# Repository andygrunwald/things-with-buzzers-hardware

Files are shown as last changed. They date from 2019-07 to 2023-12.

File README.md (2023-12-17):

# things with buzzers: hardware

Build your own hardware game show buzzers and do [awesome things](#things-you-can-do-with-buzzers) with it! 🚀

This repository contains everything you need to build hardware buzzers and connecting them with your software.
Start today having fun, and make people happy by providing them an unforgettable time.

> For even more context, we recommend reading [things with buzzers: building them](https://andygrunwald.com/blog/things-with-buzzers-building-them/).

<p align="center">
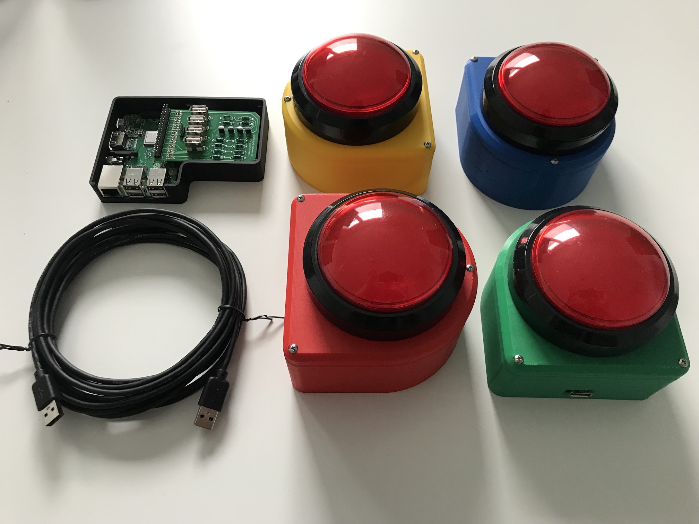
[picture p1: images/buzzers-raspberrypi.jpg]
The finished product: Four buzzers, a Raspberry Pi incl. hat
  
</p>

## Table of Contents

- [How we build and run them](#how-we-build-and-run-them)
- [What we need / Bill of materials (BOM)](#what-we-need--bill-of-materials-bom)
- [Buzzers](#buzzers)
- [Raspberry Pi Hat](#raspberry-pi-hat)
  - [GPIO pin out](#gpio-pin-out)
- [Raspberry Pi](#raspberry-pi)
- [Custom Raspberry Pi case](#custom-raspberry-pi-case)
- [How we can test the buzzers (with software)](#how-we-can-test-the-buzzers-with-software)
- [The result](#the-result)
- [Things you can do with buzzers](#things-you-can-do-with-buzzers)
- [Alternative hardware buzzer projects](#alternative-hardware-buzzer-projects)
- [Contribute](#contribute)
- [Acknowledgments](#acknowledgments)

## How we build and run them

We built four game show buzzers in four different colors (red, green, blue, yellow).
The buzzer cases are self-printed with a 3D-Printer.
Each buzzer case has a female USB connector embedded.

The central control unit is a Raspberry Pi 3 Model B+ (following _Pi_) with a custom build hat module (circuit board).
The hat module offers four female USB connectors and maps them onto the GPIO of the Pi.

Each buzzer connects via a USB cable to the Pi hat.
On the Pi, we can place software and read the buzzer signals (e.g., buzzer pressed) and react on this.

If the software (running on the Pi) offers a UI and the Pi connects to a network (or opens up a new network), a client can connect to it.
As a small software example: Show in the UI which button is pressed.

It is how it looks like:

<p align="center">
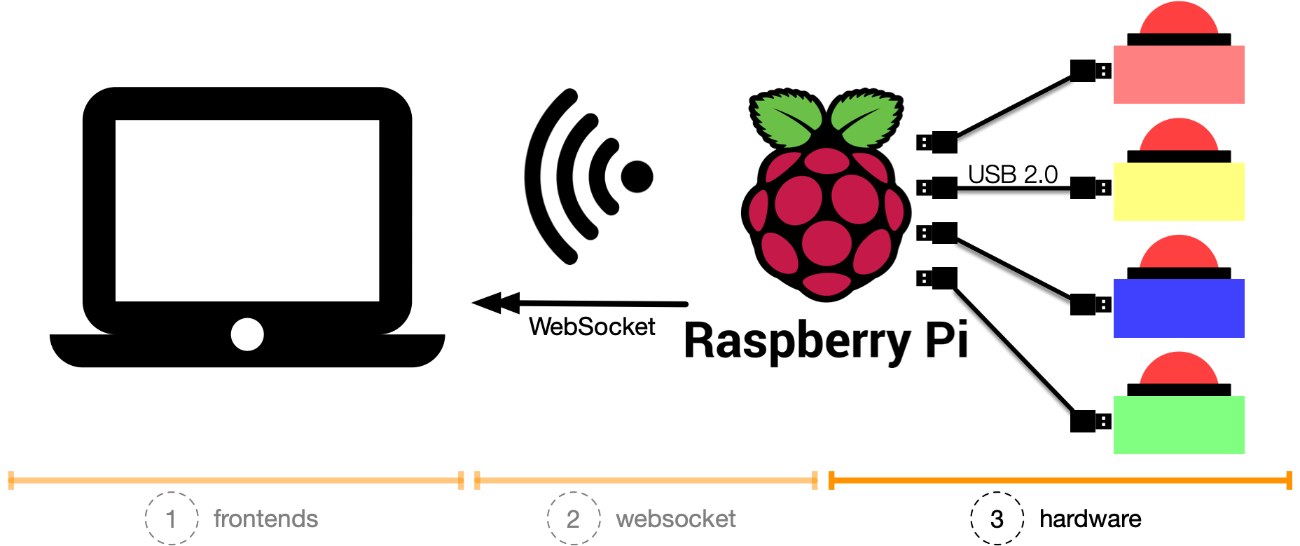
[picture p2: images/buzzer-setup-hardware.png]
The complete setup: Buzzer -> USB -> Raspberry Pi -> Computer
  
</p>

_You are missing the context, what this is all about?_
Have a look at

* [(1) things with buzzers: Jeopardy! frontend](https://github.com/andygrunwald/things-with-buzzers-jeopardy)
* [(1) things with buzzers: sports competition frontend](https://github.com/andygrunwald/things-with-buzzers-sports-competition)
* [(2) things with buzzers: websocket](https://github.com/andygrunwald/things-with-buzzers-websocket)

## What we need / Bill of materials (BOM)

To replicate this project and build your buzzers, you need a couple of things.
We have created a complete list of what you need, a so-called _Bill of material (BOM)_.

Check it out: [Bill of materials (BOM)](./bill-of-materials.md).

## Buzzers

First, we start with the buzzer case and print it with a 3D printer.
Printing instructions / Step files can be found in the [3d-models folder for the buzzer cases](./3d-models/buzzer/).
Feel free to choose the color of your printing material for the right look.
Go ahead and print!

If you are new to 3D printing, step files are printing instructions.
You can few and edit them with software like [Fusion 360 from Autodesk](https://www.autodesk.com/products/fusion-360/free-trial) (they offer [a free version for startups and hobbyists](https://www.autodesk.com/campaigns/fusion-360-for-hobbyists)).

<p align="center">
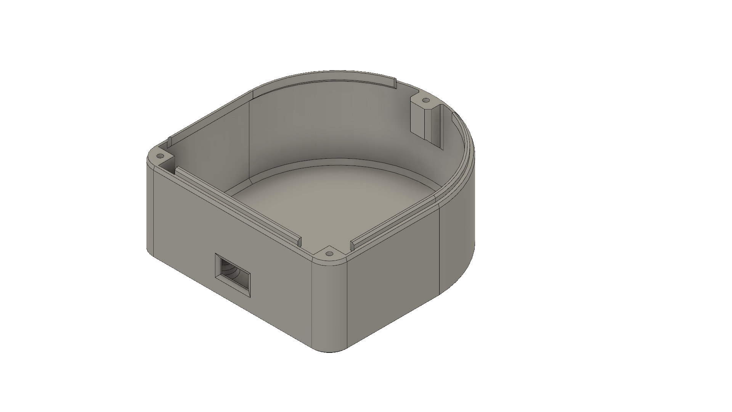
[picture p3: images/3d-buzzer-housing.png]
3D model of the buzzer case
  
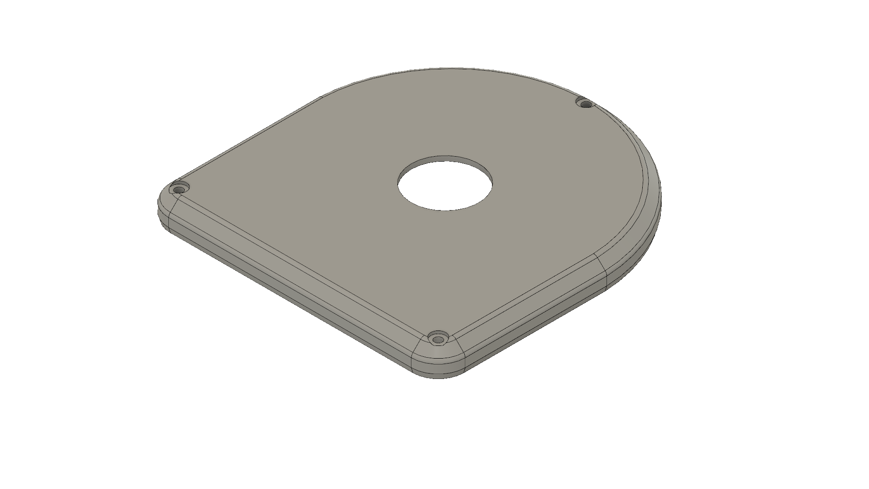
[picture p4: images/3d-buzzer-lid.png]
3D model of the buzzer lid
  
</p>

Next step would be to build the small circuit board that connects the buzzer with the USB socket:

<p align="center">
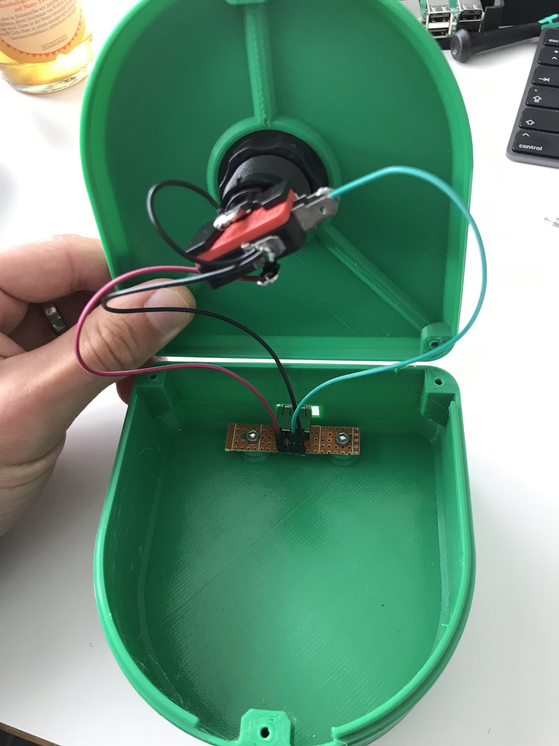
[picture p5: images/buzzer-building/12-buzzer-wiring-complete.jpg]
Buzzer wired internally
  
</p>

Check out the **step-by-step image guide on how to build this** in our [buzzer building folder](./images/buzzer-building/README.md).

Congratulations, you build your first game show buzzer. How awesome is this?

## Raspberry Pi Hat

Second, we build our custom Pi hat.
The buzzers are connected to the GPIO on the Raspberry Pi.
For convenience reasons, we built a custom Pi hat with USB sockets.
This makes it easier to assemble and disassemble the setup.

<p align="center">
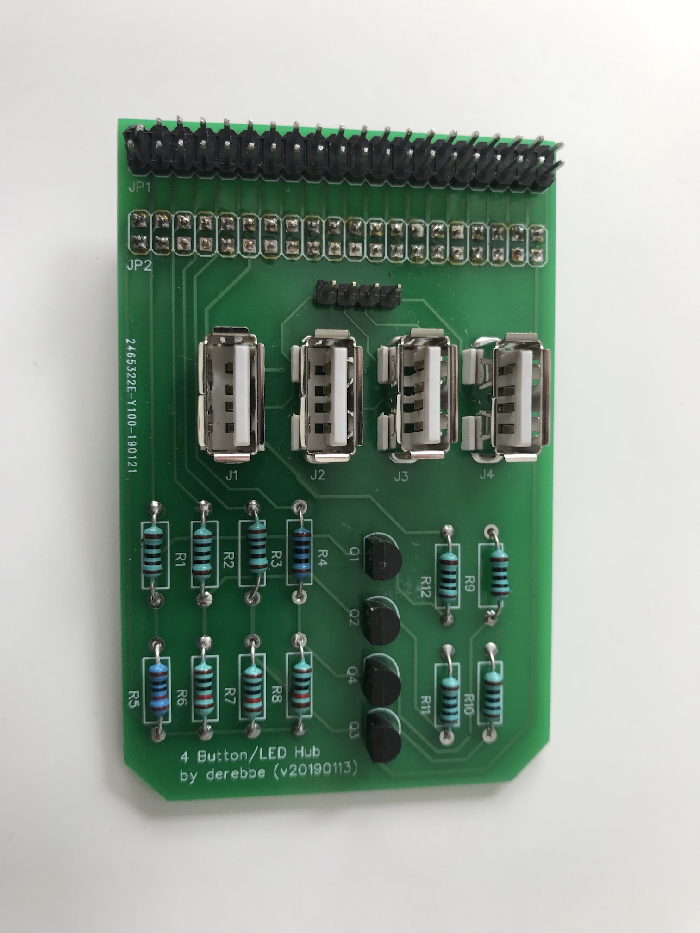
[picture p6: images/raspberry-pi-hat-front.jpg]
Raspberry Pi hat front view
  
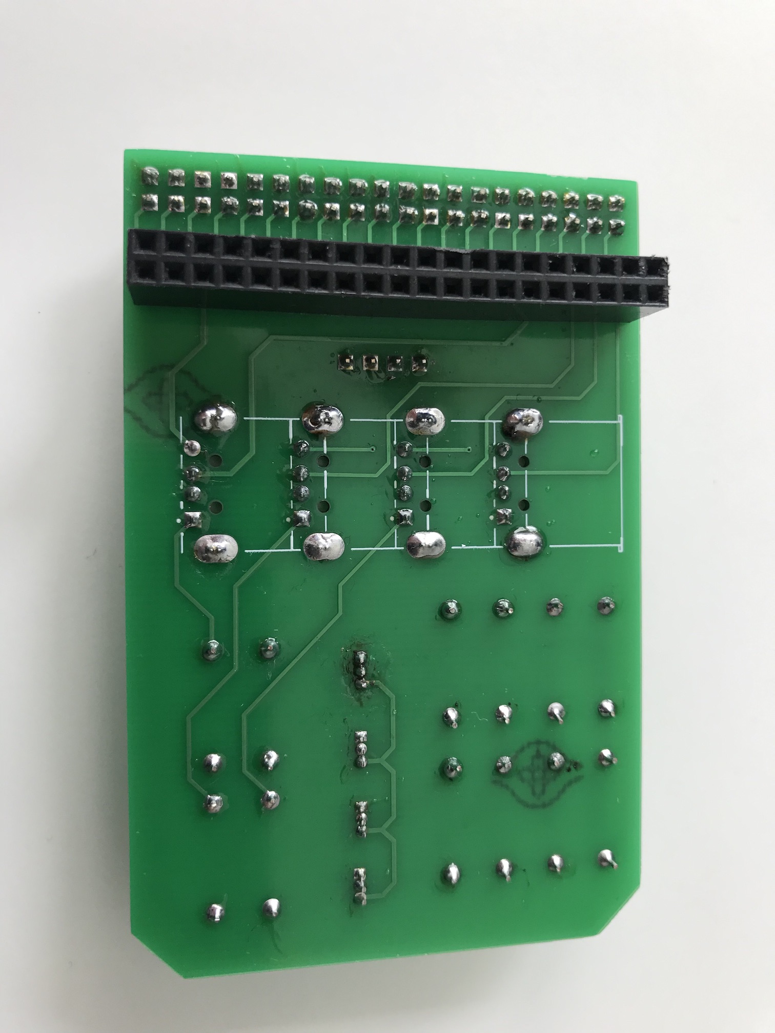
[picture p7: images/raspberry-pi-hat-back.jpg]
Raspberry Pi hat back view
  
</p>

We used [EasyEDA](https://easyeda.com/) to design the printed circuit board (PCB).
**We made the project public. Check it out at [RPI 4Button LED HUB from derebbe @ EasyEDA](https://easyeda.com/derebbe/RPI-4Button-LED-HUB)**.

The EasyEDA project shows you which resistor, transistor or pin has to be placed.
Furthermore, you can [order the pre-designed PCB at EasyEDA](https://docs.easyeda.com/en/PCB/Order-PCB).
Pre-designed, in this case, means: You get the circuit board and need to place the components on it.
All wholes are pre-defined, and all components are connected already.

If you want to create the circuit board on your own, you can find all Gerber files in our [Raspberry Pi Hat Gerber folder](./raspberry-pi-hat-gerber/).
You can also do a fresh export from [our project on EasyEDA](https://easyeda.com/derebbe/RPI-4Button-LED-HUB).

If this is done, place the hat on the GPIOs on top of the Raspberry Pi.
By this, you are good to go!

### GPIO pin out

Placing the hat on the pi, you connect the buzzers with the GPIO.
To react with your software on buzzer pushed, you need to know which pins your software need to listen on.
The [GPIO pin out assignment](https://www.raspberrypi.org/documentation/usage/gpio/) looks like the following:

| USB Port  | GPIO Pin (BCM) | GPIO Pin (Physical) | Purpose |
| --- | --- | --- | --- |
| Port #1 | 21 | 40 | Button  |
| Port #1 | 26 | 37 | LED |
| Port #2 | 20 | 38 | Button  |
| Port #2 | 19 | 35 | LED |
| Port #3 | 16 | 36 | Button  |
| Port #3 | 13 | 33 | LED |
| Port #4 | 12 | 32 | Button  |
| Port #4 | 6 | 31 | LED |

The [pin-out mapping from the go-rpio documentation](https://godoc.org/github.com/stianeikeland/go-rpio) is super helpful.

## Raspberry Pi

Third and last step lets set up the Pi!
On the Raspberry Pi (following _Pi_) itself, we install a [standard Raspbian Lite operating system](https://www.raspberrypi.org/downloads/raspbian/) without any desktop functionality.

To access the Pi from an external client (e.g., laptop or mobile phone) you should connect it to a network.
Either to an existing one via a typical RJ45 LAN cable or a wireless network (can be done via [`raspi-config`](https://www.raspberrypi.org/documentation/configuration/raspi-config.md)).
If you want to run it completely independent and maybe offline, we recommend to [configure the Pi as a wireless access point](https://www.raspberrypi.org/documentation/configuration/wireless/access-point.md).

Add the Pi hat onto the GPIO and move on to your first software tests.

## Custom Raspberry Pi case

A Pi with a hat consumes more space.
Especially with a custom hat, it is hard to find a case that fits.
That's why we printed our own.

Printing instructions / Step files can be found in the 3d-models folder for the raspberry pi case.
Feel free to choose the color of your printing material for the right look.
Go ahead and print!

<p align="center">
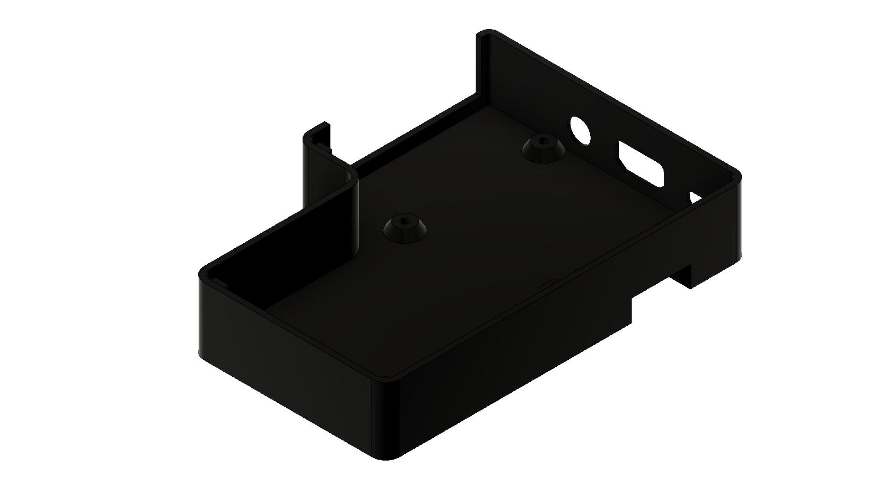
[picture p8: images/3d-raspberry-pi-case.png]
3D model of the custom Raspberry Pi case
  
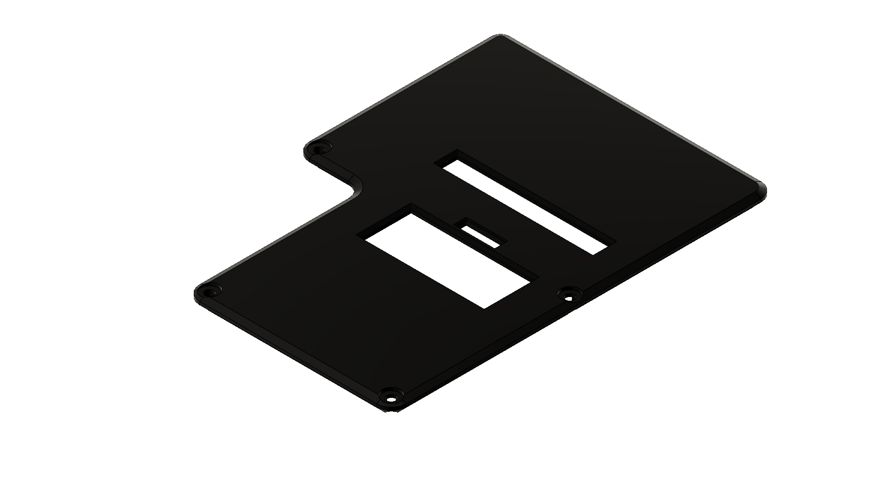
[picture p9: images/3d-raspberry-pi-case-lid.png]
3D model of the custom Raspberry Pi case lid
  
</p>

## How we can test the buzzers (with software)

Set everything up.
Connect the buzzers with the Raspberry Pi and start the machine.
It is time to test our new hardware with software ❤️.

Have a look at our test scripts and test applications.
Choose the one you like the most (or by roll a dice):

* [test script written in Python 🐍](./software/python/)
* [test application written in Go](./software/go/)

If everything works out, it is okay to freak out and run naked through your flat.
You deserved it. You have built the foundation for more.
Don't stop. Find out [what you can do with buzzers](#things-you-can-do-with-buzzers).

## The result

We have set up a quick demo setup.
Have a quick look at this video: [things with buzzers: hardware showcase @ YouTube](https://youtu.be/pAQNX0Fhxk4).

## Things you can do with buzzers

* [Running a Jeopardy! game show](https://andygrunwald.com/blog/things-with-buzzers-playing-jeopardy/)
* [Stopping athletes time during a sports event](https://andygrunwald.com/blog/things-with-buzzers-a-sports-competition/)

## Alternative hardware buzzer projects

* [Slim one handed buzzers by Ross and Garrett](https://github.com/gdsimco/JParty-with-buzzers/blob/8b5948cd840acf981036fda1b671626e5d60780b/physicalbuzzers/README.md)

## Contribute

If you are a maker or an engineer or just someone who wants to create and ship awesome things: *Go ahead and make this better*.
Feel free to fork it and play your changes back via a [Pull Request](https://help.github.com/en/articles/about-pull-requests).

If you ...
* are unsure
* plan to do a more significant rework
* want to get feedback about the idea before you put the effort in

[Open an issue](https://github.com/andygrunwald/things-with-buzzers-hardware/issues/new) and let us talk about your idea.

You have built your own buzzers and did awesome things with it?
Write an article in your blog, or tell us the story in an issue or make a Pull Request with a Markdown file.
But tell us. Let us know. Inspire us!

We believe that we can do more together. Let's to it together! 🚀

## Acknowledgments

A big thank you to [Lars Heß / @lhess](https://github.com/lhess) and [Matthias Endler / @mre](https://github.com/mre).
Without them, this project would not happen.

Lars has designed and built the complete hardware.
Matthias helped a lot with the software and motivation part 😀

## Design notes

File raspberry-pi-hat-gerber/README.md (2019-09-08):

# Raspberry Pi Hat Gerber Files

_If you don't know what this is, have a look at the [main README](../README.md)_

Gerber files to build the Rasberry Pi Hat shown below.
Also available at the [RPI 4Button LED HUB from derebbe @ EasyEDA](https://easyeda.com/derebbe/RPI-4Button-LED-HUB) project.

<p align="center">
  Raspberry Pi hat front view
</p>

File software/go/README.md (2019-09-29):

# Go test application

_If you don't know what this is, have a look at the [main README](../../README.md)_

The test application is written in [Go](https://golang.org/).

## Compile it for the Raspberry Pi

```sh
GOARM=7 GOARCH=arm GOOS=linux go build -o "twb-hardware-buzzer-push"
```

## Deployment on your Raspberry Pi

If you are on a Mac or Linux machine, you can deploy this script by using `scp` onto your Raspberry Pi:

```sh
scp -r twb-hardware-buzzer-push pi@192.168.4.1:twb-hardware-buzzer-push
```

In our example, the target Pi has the IP address `192.168.4.1`.

## Start the application

Login into the Pi, switch to the correct folder, and execute:

```sh
sudo ./twb-hardware-buzzer-push
```

## The result

If everything works fine, the result should look like ...

<p align="center">
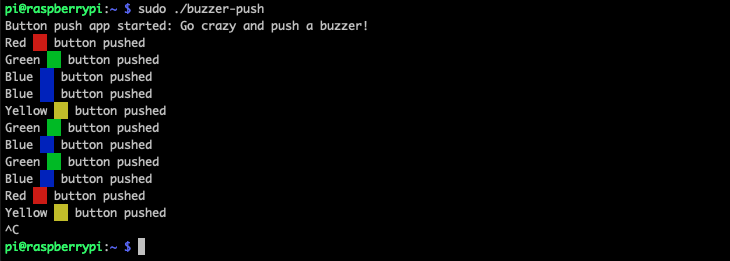
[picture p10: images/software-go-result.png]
Result of the software test with Go
  
</p>

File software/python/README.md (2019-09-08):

# Python test script

_If you don't know what this is, have a look at the [main README](../../README.md)_

The test script is written in [Python](https://www.python.org/).

## Deployment on your Raspberry Pi

If you are on a Mac or Linux machine, you can deploy this script by using `scp` onto your Raspberry Pi:

```sh
scp -r * pi@192.168.4.1:python-test/
```

In our example, the target Pi has the IP address `192.168.4.1`.

## Start the script

Login into the Pi, switch to the correct folder, and execute:

```sh
sudo python button-push.py
```

## The result

If everything works fine, the result should look like ...

<p align="center">
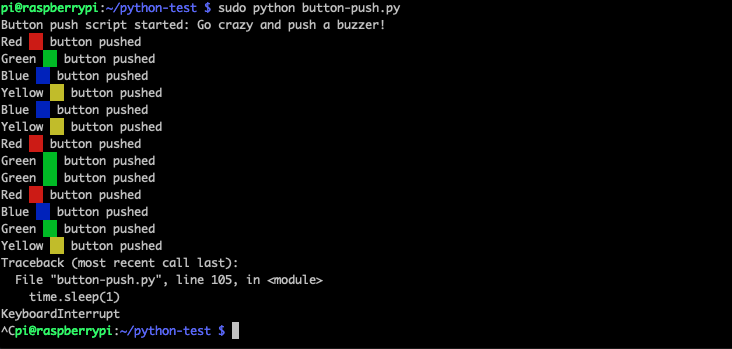
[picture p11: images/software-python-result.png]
Result of the software test with Python
  
</p>

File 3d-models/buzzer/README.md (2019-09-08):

# 3D Models for the buzzer case

_If you don't know what this is, have a look at the [main README](../../README.md)_

Step files to 3D print a case for game show buzzers.

<p align="center">
  3D model of the buzzer case
  3D model of the buzzer lid
</p>

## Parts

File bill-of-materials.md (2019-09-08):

# Bill of materials (BOM)

_If you don't know what this is, have a look at the [main README](README.md)_

Everything that you need to build your buzzers and replicate this project.

We aim to categorize the materials per component.
The links are just for showcase reasons and might not link to the cheapest shops.
Please do your research depending on your country of living where to buy the materials best.

PS: If you don't own everything yourself (like more expensive equipment like a 3D printer, you can reach out to a local [Hackerspace](https://en.wikipedia.org/wiki/Hackerspace) or a [Fab lab](https://en.wikipedia.org/wiki/Fab_lab) in your area.

## General equipment

Things you need in general:

* A Soldering iron and solder
* Fine mechanics tooling to work with electronic components (e.g., cables, resistor)
* A 3D printer

## Buzzer

This list of materials is to build one buzzer.
Please multiply it according to the number of buzzers you want to build.

* Print material for a 3D printer in a color of your choice (the button case)
* The buzzer itself (e.g., on [ebay germany](https://www.ebay.de/itm/100mm-Selbstruck-Convex-Taster-Spiel-Vending-Machine-Control-Microswitch/182433206826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) or [AliExpress](https://www.aliexpress.com/item/32757761221.html?spm=a2g1y.12024536.productList_117902197.pic_9)) - Make sure that they are 100mm big and not the small arcade buttons
* [A USB male connector](https://www.amazon.com/USB-Connector-Conwork-Straight-Replacement/dp/B072MCHX41?th=1)
* [Breadboard jumper wires](https://www.amazon.com/Foxnovo-Breadboard-Jumper-Wires-Female/dp/B00PBZMN7C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)
* [Pin header connectors](https://www.amazon.com/Glarks-Connector-Assortment-Stackable-Breakaway/dp/B07CWSXY7P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)
* A small piece of a [circuit board](https://www.amazon.com/uxcell-Universal-Printed-Circuit-Soldering/dp/B07FK6TDD5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) (to cut and solder)
* Three small screws

## Raspberry Pi hat

The Pi hat is only needed and built once (for four buzzers).

PS: The circuit board itself (without components on it) is fully designed at [our EasyEDA project](https://easyeda.com/derebbe/RPI-4Button-LED-HUB) and can be ordered from there. By this, you don't have to connect the components by yourself, only add them onto the board.

* A [circuit board](https://www.amazon.com/uxcell-Universal-Printed-Circuit-Soldering/dp/B07FK6TDD5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) (to cut and solder)
* 4 x [USB male connector](https://www.amazon.com/USB-Connector-Conwork-Straight-Replacement/dp/B072MCHX41?th=1)
* 4 x resistor 100Ω
* 4 x resistor 10KΩ
* 4 x resistor 470Ω
* 4 x transistor npn (BJT)
* 1 x male 2x20 [Pin Headers](https://www.amazon.com/dp/B074HVBTZ4/ref=psdc_172544_t2_B07CWSXY7P)
* 1 x female 2x20 [Pin Headers](https://www.amazon.com/dp/B074HVBTZ4/ref=psdc_172544_t2_B07CWSXY7P)
* 1 x male 1x4 [Pin Headers](https://www.amazon.com/dp/B074HVBTZ4/ref=psdc_172544_t2_B07CWSXY7P)

## Miscellaneous

* A Raspberry Pi 3 Model B+ (or a newer one with the same layout)
* 5m USB 2.0 cables (don't need to be the best quality when it comes to data transfer speed, we only use USB for convenience reasons and to transfer the push signal)

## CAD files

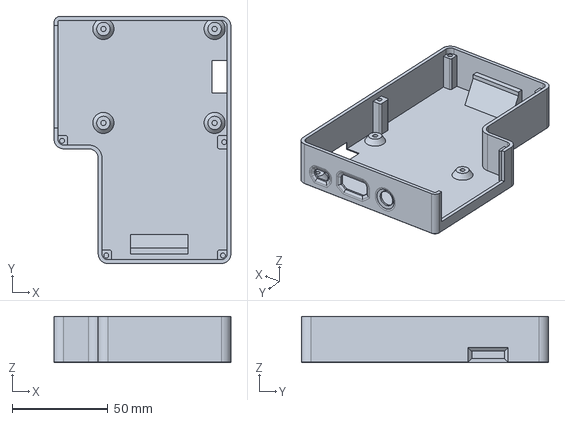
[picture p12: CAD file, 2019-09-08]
3d-models/raspberry-pi-case/CaseMain.step
92.2 x 128.8 x 24.0 mm

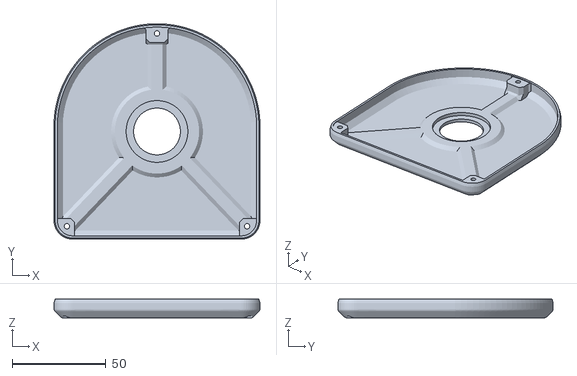
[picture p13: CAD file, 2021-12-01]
3d-models/buzzer/BuzzerLidV2.stl
110.0 x 115.0 x 10.0

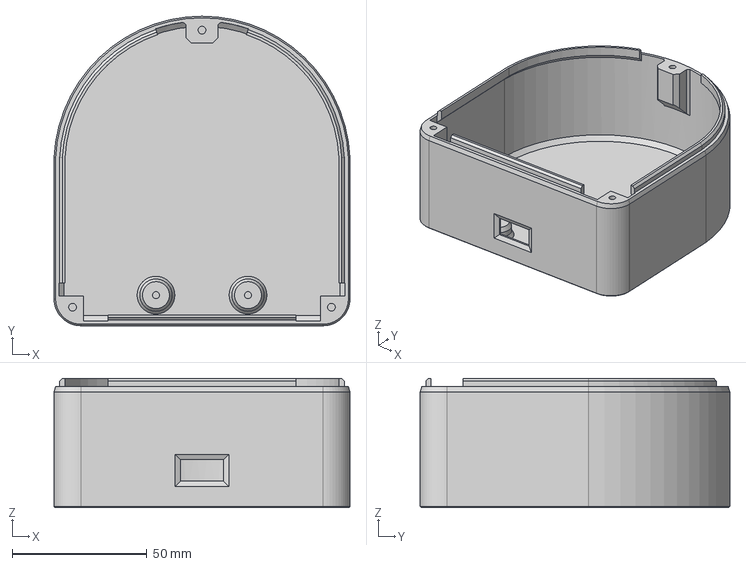
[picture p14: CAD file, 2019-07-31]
3d-models/buzzer/BuzzerHousing.stp
110.0 x 115.1 x 48.0 mm

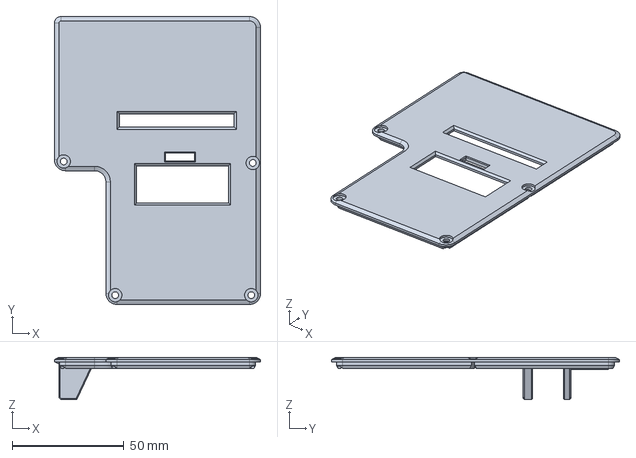
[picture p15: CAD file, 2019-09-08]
3d-models/raspberry-pi-case/CaseLid.step
92.2 x 128.8 x 19.0 mm

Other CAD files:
3d-models/buzzer/BuzzerLid.stp
3d-models/buzzer/BuzzerHousing.stl

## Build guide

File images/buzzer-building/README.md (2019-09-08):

# Buzzer building

_If you don't know what this is, have a look at the [main README](../../README.md)_.

The images will show you how to build the circuit board, which will connect the buzzer with a USB socket.

The following three images are showing you how it looks like:
It contains four male pin headers.
Each pin is connected to one pin of the USB socket.
One USB cable has four wires. We only use three (1 x for the LED in the button, 1 x for the button itself and one for ground (GND)).

<p align="center">
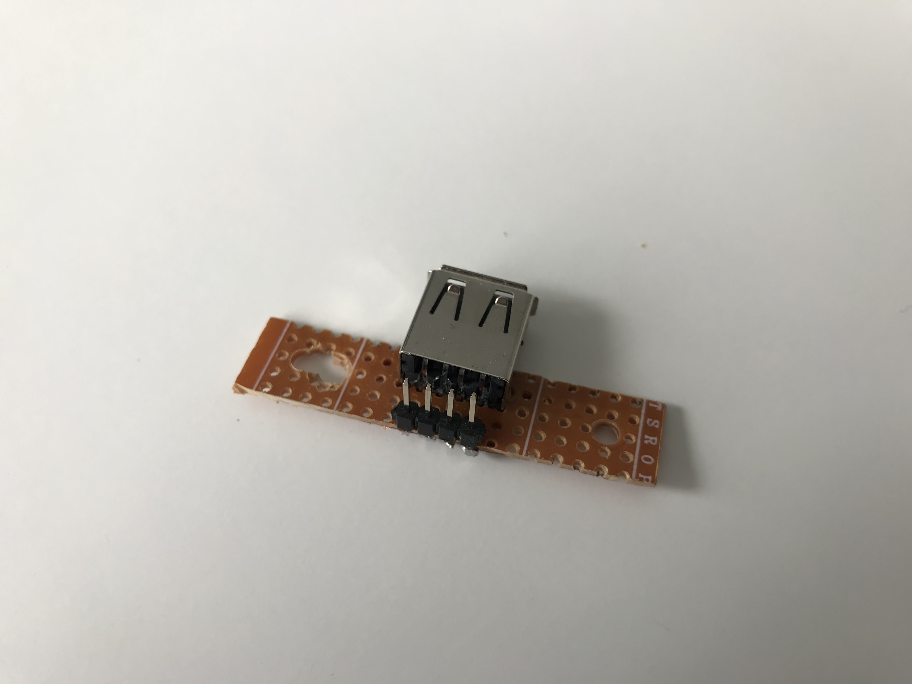
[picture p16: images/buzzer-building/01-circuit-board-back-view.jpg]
Circuit board back view
  
</p>

<p align="center">
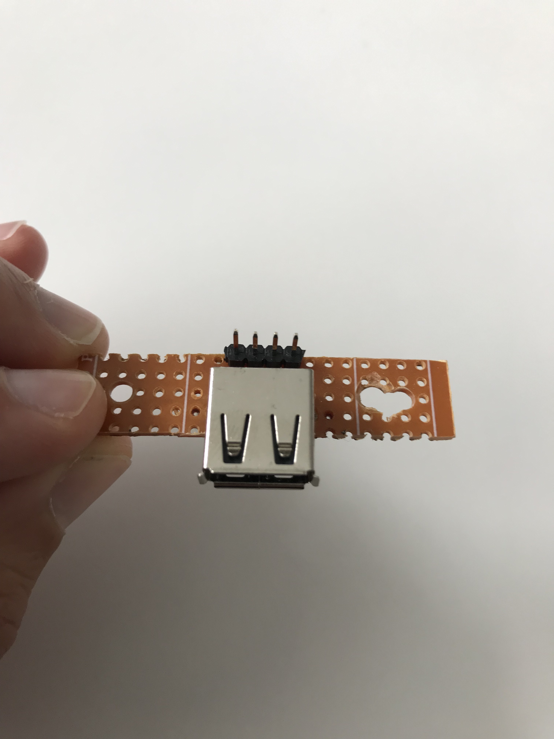
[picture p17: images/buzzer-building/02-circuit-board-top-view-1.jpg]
Circuit board top view 1
  
</p>

<p align="center">
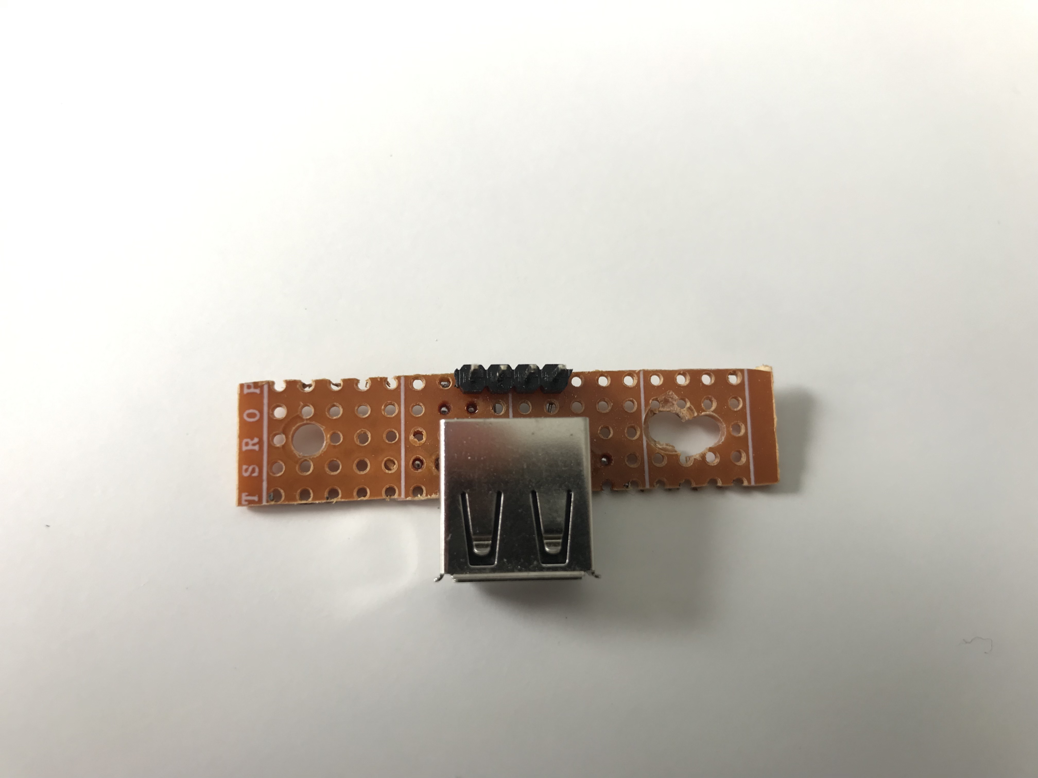
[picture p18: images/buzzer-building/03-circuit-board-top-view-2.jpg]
Circuit board top view 2
  
</p>

Here you can see how we connect the header pins with the USB socket (by adding tin-solder).

<p align="center">
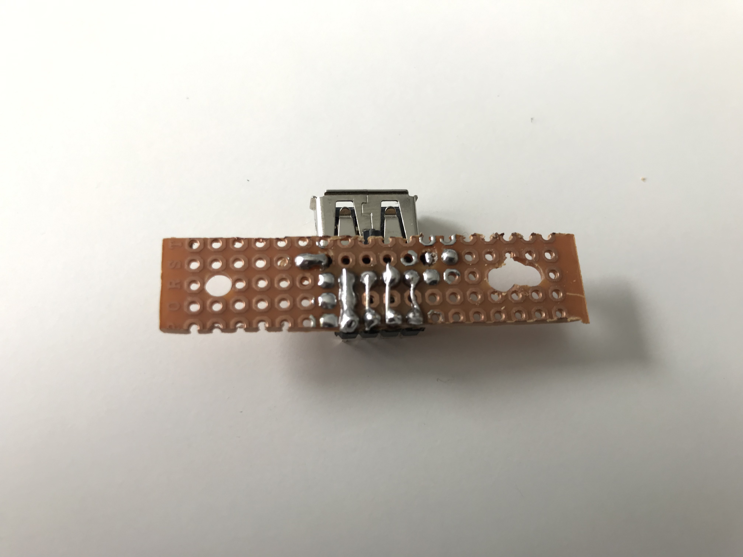
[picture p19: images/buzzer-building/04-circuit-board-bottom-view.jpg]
Circuit board bottom view
  
</p>

Once the circuit board is done, you fixate it:

<p align="center">
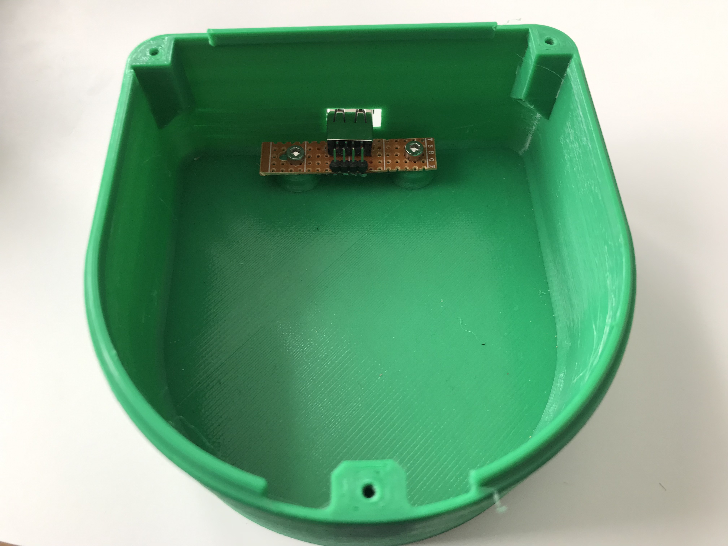
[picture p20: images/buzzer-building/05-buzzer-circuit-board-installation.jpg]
Buzzer circuit board installation
  
</p>

<p align="center">
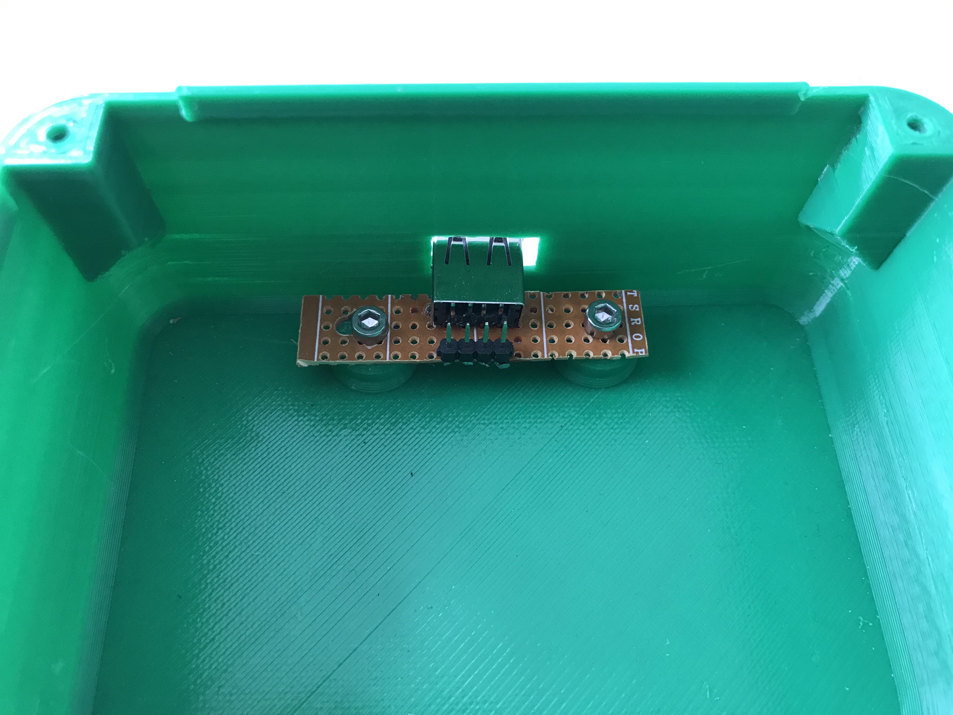
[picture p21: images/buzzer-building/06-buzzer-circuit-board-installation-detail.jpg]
Buzzer circuit board installation (detail)
  
</p>

The next step would be to add the buzzer onto our printed lid:

<p align="center">
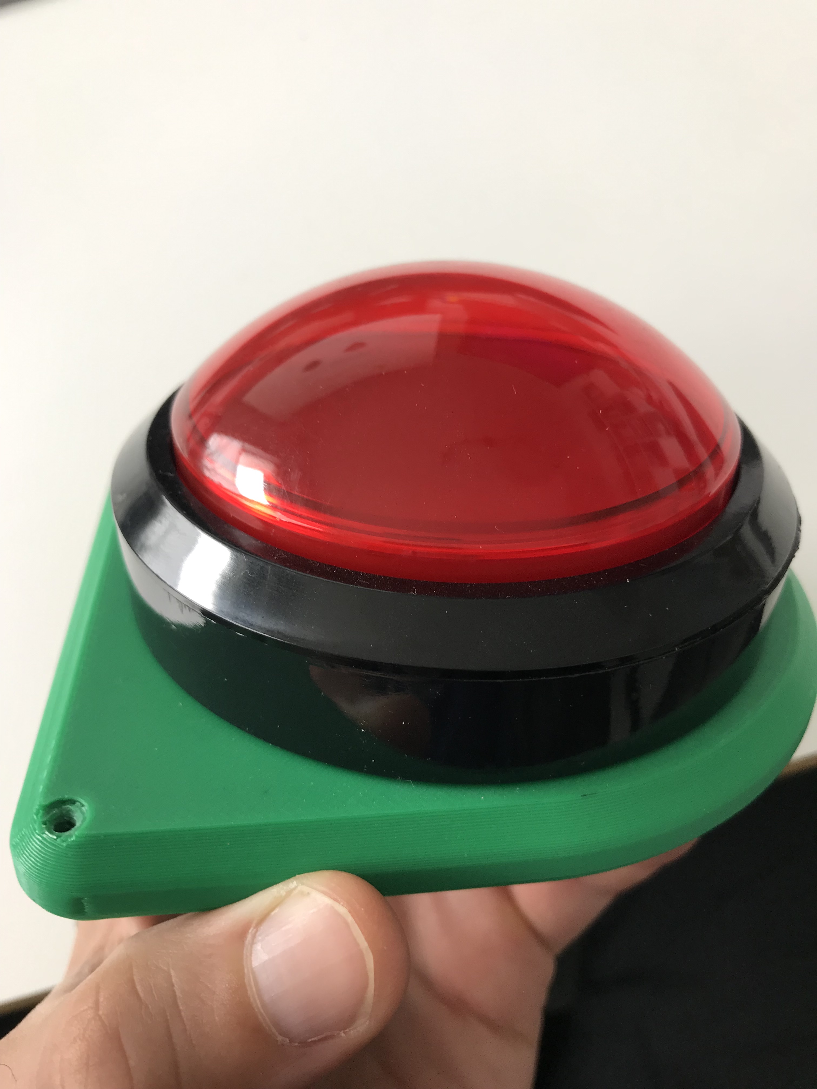
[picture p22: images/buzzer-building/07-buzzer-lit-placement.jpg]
Buzzer placement on the lit
  
</p>

Add the breadboard jumper wires to the buzzer like shown below.
If you plan to build multiple buzzers, we suggest always using the same cable colors for the same purpose.
In our pictures, we used:

* a red 🔴 jumping wire for the LED (voltage)
* a green 🍏 jumping wire for the Button
* a black ⚫ jumping wire for the ground (GND)

<p align="center">
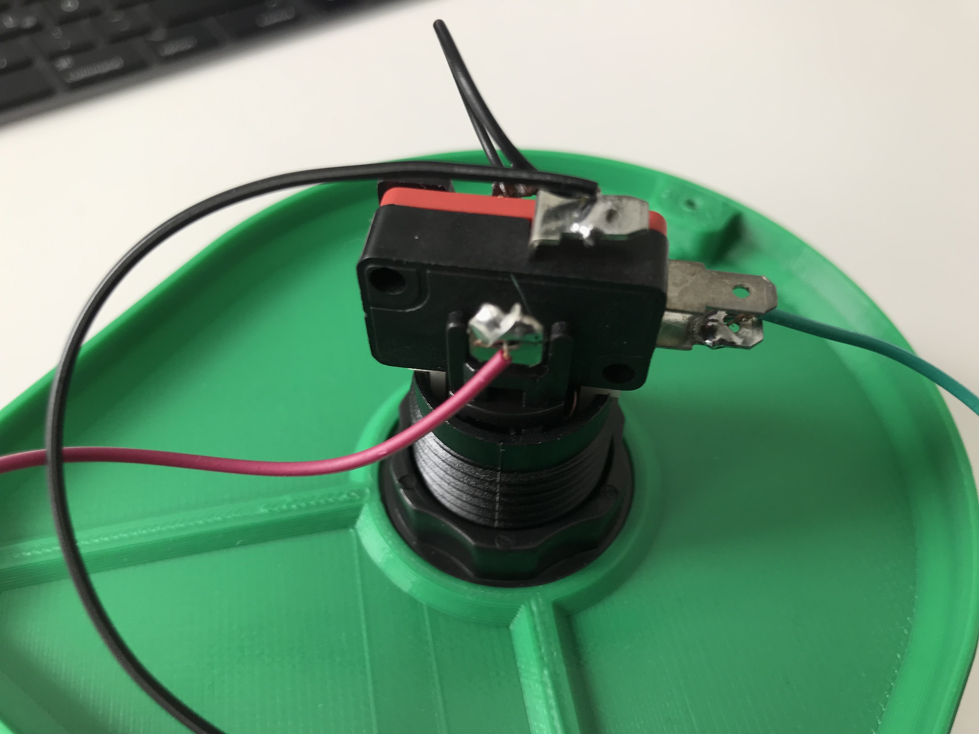
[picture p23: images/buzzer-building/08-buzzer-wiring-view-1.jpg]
Buzzer wiring view 1
  
</p>

<p align="center">
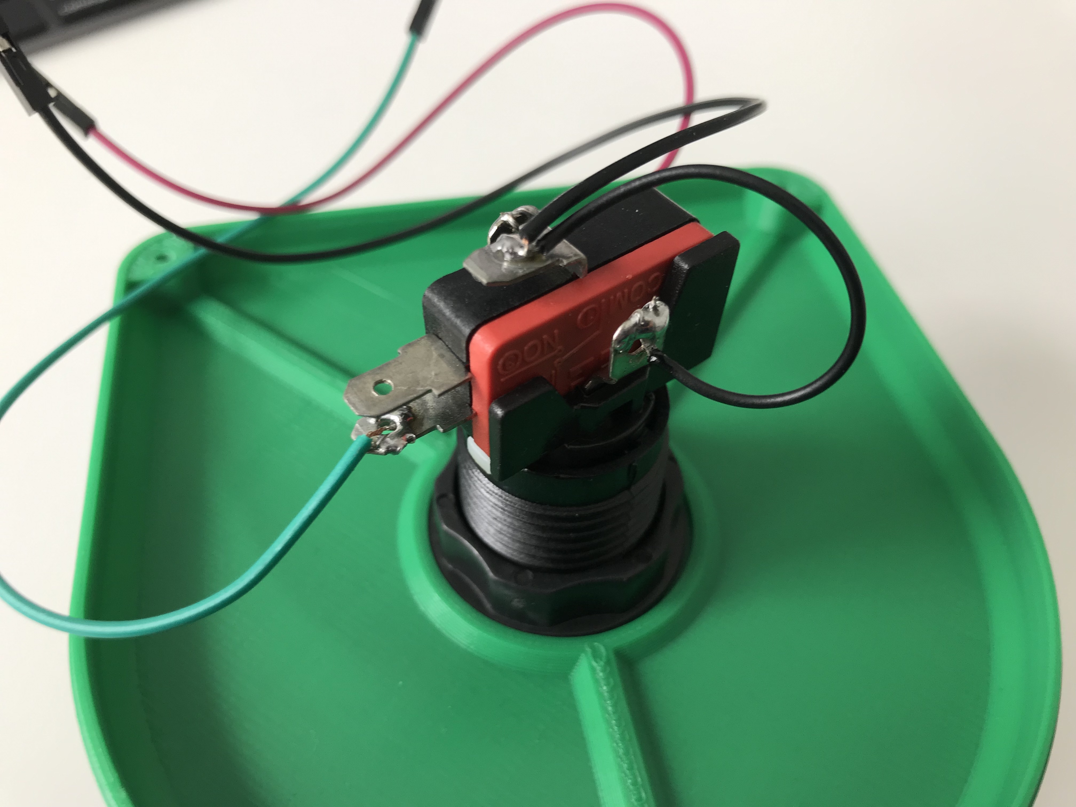
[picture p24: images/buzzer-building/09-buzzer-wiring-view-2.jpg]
Buzzer wiring view 2
  
</p>

Connect the button with the previously built circuit board.
Please keep the order of the wires in line.
This is important.

<p align="center">
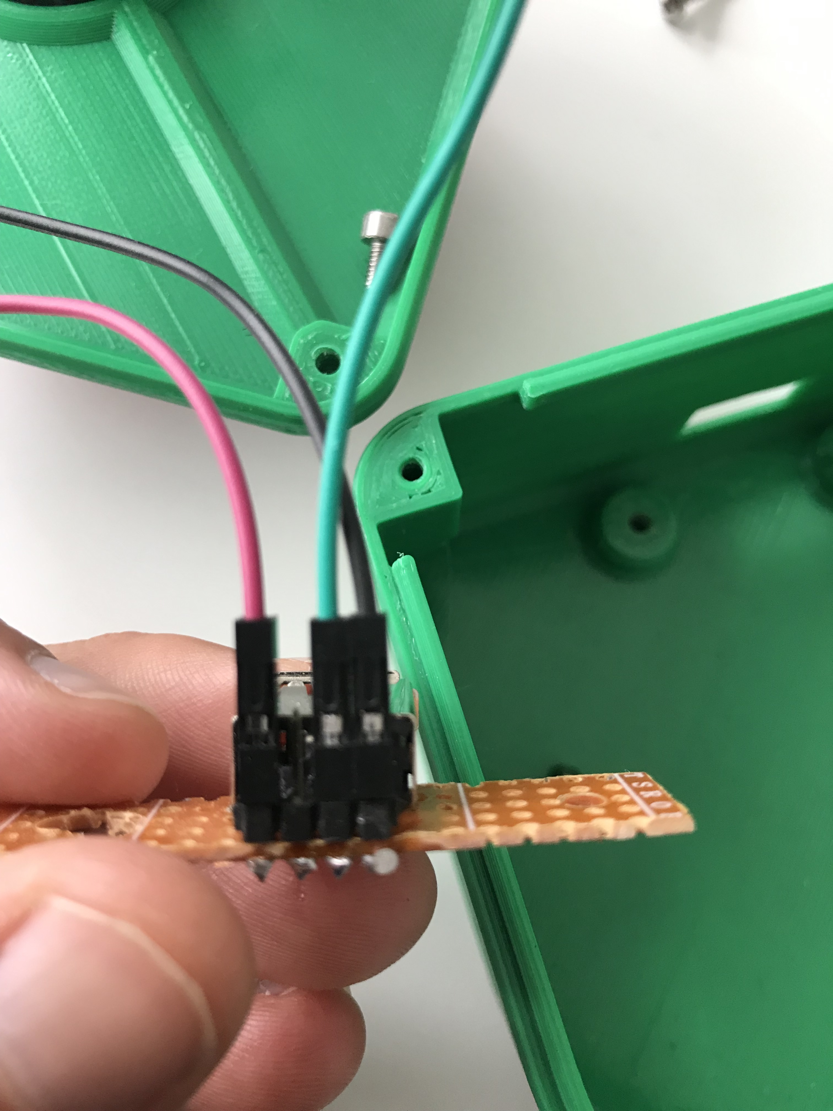
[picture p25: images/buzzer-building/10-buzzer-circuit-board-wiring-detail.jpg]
Buzzer <-> Circuit board wiring (detail)
  
</p>

<p align="center">
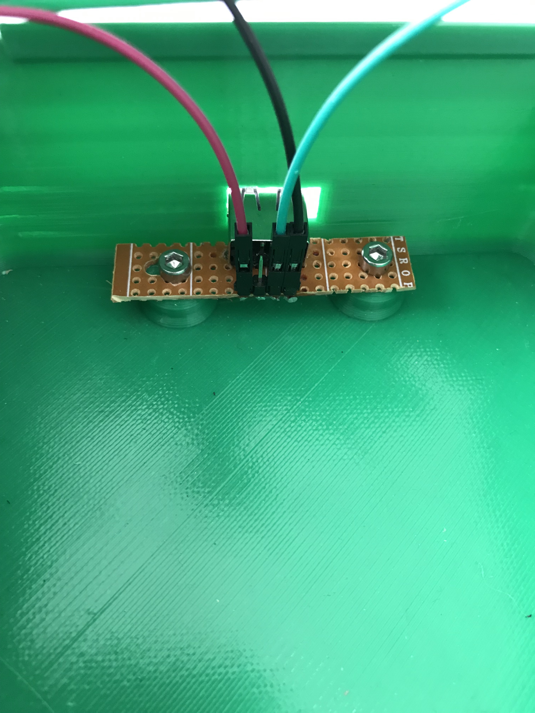
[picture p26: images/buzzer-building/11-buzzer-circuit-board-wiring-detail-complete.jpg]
Buzzer <-> Circuit board wiring (detail / complete)
  
</p>

This is how the result looks like:

<p align="center">
  Buzzer wiring complete
</p>

Close the buzzer with three screws and you are done. Congratulations!

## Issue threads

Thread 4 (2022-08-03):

Hardware discrepencies

Gruffers, 2022-08-03:
On the BoM, Male USB connectors are listed, they it should read Female USB connectors and if people are going to follow the build the USB connectors need to be 4 Pin and they will need a total of 8, with 4 of them being 90 degrees for the buttons and 4 of them being 180 degrees for the Pi hat.

Getting into the specifics of the resistors, adding 1/2 W as prescribed in your EasyEDA project helps.
    - 4 x resistor 100Ω 1/2 Watt
    - 4 x resistor 10KΩ  1/2 Watt
    - 4 x resistor 470Ω 1/2 Watt

The transistor model is 2N3904
    - 4 x transistor npn (BJT) 2N3904

What remains unclear is Pi hat.  Looking closely at the photographed example, it appears that the Pi hat is different than the Pi hat designed in the gerber files.  The 4 pin header is the obvious deviation.

For the Pi Hat, the placement of the resistors is unclear.  Since there are no 470 Ohm resistors on the example, it will take some testing to determine if they are needed and whether they belong in R1-R4 or R9-R12..

R1 - 100 Ohm
R2 - 100 Ohm
R3 - 100 Ohm
R4 - 100 Ohm

R5 - 10k Ohm
R6 - 10k Ohm
R7 - 10k Ohm
R8 - 10k Ohm

R9 - 100 Ohm
R10 - 100 Ohm
R1 1- 100 Ohm
R12 - 100 Ohm

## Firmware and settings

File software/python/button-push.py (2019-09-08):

#
# Small script to test the functionality of the hardware buzzers. 
#
# We use the well-known RPi.GPIO library for the use case.
# Check out more about the library here: https://pypi.org/project/RPi.GPIO/
#
import os
import RPi.GPIO as GPIO
import time
import subprocess

# Define Raspberry PI GPIO pins for all four buttons.
# These pins are for the button itself.
PIN_BTN_RED = 21
PIN_BTN_GREEN = 20
PIN_BTN_BLUE = 16
PIN_BTN_YELLOW = 12

# These pins are for the LEDs inside the button.
PIN_LED_RED = 26
PIN_LED_GREEN = 19
PIN_LED_BLUE = 13
PIN_LED_YELLOW = 6

# Set the right GPIO pin layout.
# See "What is the difference between BOARD and BCM for GPIO pin numbering?"
# https://raspberrypi.stackexchange.com/questions/12966/what-is-the-difference-between-board-and-bcm-for-gpio-pin-numbering
GPIO.setmode(GPIO.BCM)

# Set input signals for the buttons.
GPIO.setup(PIN_BTN_RED, GPIO.IN, pull_up_down=GPIO.PUD_UP)
GPIO.setup(PIN_BTN_GREEN, GPIO.IN, pull_up_down=GPIO.PUD_UP)
GPIO.setup(PIN_BTN_BLUE, GPIO.IN, pull_up_down=GPIO.PUD_UP)
GPIO.setup(PIN_BTN_YELLOW, GPIO.IN, pull_up_down=GPIO.PUD_UP)

# Set output signals for the LEDs.
GPIO.setup(PIN_LED_RED, GPIO.OUT)
GPIO.output(PIN_LED_RED, GPIO.LOW)
GPIO.setup(PIN_LED_GREEN, GPIO.OUT)
GPIO.output(PIN_LED_GREEN, GPIO.LOW)
GPIO.setup(PIN_LED_BLUE, GPIO.OUT)
GPIO.output(PIN_LED_BLUE, GPIO.LOW)
GPIO.setup(PIN_LED_YELLOW, GPIO.OUT)
GPIO.output(PIN_LED_YELLOW, GPIO.LOW)

# Store the status of the LEDs.
# Default, all leds are off.
leds = {
    PIN_LED_RED: False,
    PIN_LED_GREEN: False,
    PIN_LED_BLUE: False,
    PIN_LED_YELLOW: False
}
def buttonDown(channel):
    """
    Print which button was hit and trigger the related LED.
    If the LED is off (default), switch it on when the button is hit.
    If the LED is on (e.g., after the first button hit), switch it off.

    `channel` is the GPIO pin number of the hit button.
    """
    global leds 

    # Print which button color was hit.
    buttons = {
        PIN_BTN_RED: "Red \033[41m  \033[0m",
        PIN_BTN_GREEN: "Green \033[42m  \033[0m",
        PIN_BTN_BLUE: "Blue \033[44m  \033[0m",
        PIN_BTN_YELLOW: "Yellow \033[1;43m  \033[0m"
    }
    output = buttons.get(channel, "Unknown button colour")
    output += " button pushed"
    print(output)

    # Create a relation which button hit needs 
    # to activate which LED.
    button_led_mapping = {
        PIN_BTN_RED: PIN_LED_RED,
        PIN_BTN_GREEN: PIN_LED_GREEN,
        PIN_BTN_BLUE: PIN_LED_BLUE,
        PIN_BTN_YELLOW: PIN_LED_YELLOW
    }

    # Determine the right LED per button.
    led = button_led_mapping.get(channel, "Unknown button")
    led_status = leds.get(led, "Unknown button led")
    if (led_status == True):
        leds[led] = False
        GPIO.output(led, GPIO.LOW)
    else:
        leds[led] = True
        GPIO.output(led, GPIO.HIGH)

# Add event listener to detect input signals from the buttons.
# In case of button hit, execute the callback.
GPIO.add_event_detect(PIN_BTN_RED, GPIO.RISING, callback=buttonDown, bouncetime=300)
GPIO.add_event_detect(PIN_BTN_GREEN, GPIO.RISING, callback=buttonDown, bouncetime=300)
GPIO.add_event_detect(PIN_BTN_BLUE, GPIO.RISING, callback=buttonDown, bouncetime=300)
GPIO.add_event_detect(PIN_BTN_YELLOW, GPIO.RISING, callback=buttonDown, bouncetime=300)

# Start the main loop keep it running.
print("Button push script started: Go crazy and push a buzzer!")
try:
    while True:
        time.sleep(1)
finally:
    GPIO.cleanup()

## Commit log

2019-07-31 Add information about button wiring
2019-07-31 Added 3d model files and schema for the button led circuit board
    [BuzzerHousing.stp, BuzzerLid.stp]
2019-09-08 Replaced ASCII smiley with 😀 emoji in the credits chapter
2019-09-08 Add chapter about the Raspberry Pi
2019-09-08 Add chapter Bill of materials (BOM)
2019-09-08 Add first part of the creating the buzzer chapter
    [BuzzerHousing.stp, BuzzerLid.stp]
2019-09-08 Add detail image guide for buzzer wiring
2019-09-08 Add chapter about building the Raspberry Pi Hat
    [Gerber_BoardOutline.GKO, Gerber_BottomLayer.GBL, Gerber_BottomSilkLayer.GBO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]
2019-09-08 Fixed a broken sentence in bill-of-materials
2019-09-08 Add deep link sentence to bill of materials
2019-09-08 Fix deeplink link for bill of materials
2019-09-08 Add voltage information to LED wire
2019-09-08 Add GPIO pin out documentation to Raspberry Pi hat chapter
2019-09-08 Add chapter about Custom Raspberr Pi case
    [BuzzerHousing.stp, BuzzerLid.stp, CaseLid.step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]
2019-09-23 Added internal buzzer wiring to README.md
2019-09-29 Add physical GPIO pin layout
2019-10-02 Add funding.yml for sponsoring button
2019-11-01 Add a couple of blog posts
2019-11-04 Add second version (a little bit more stable) of Buzzer lid
    [BuzzerLidV2.stl]
2021-11-30 Added busser housing STL file
    [BuzzerHousing.stl]
2021-11-30 Fix positioning of buzzer lid v2 STL
    [BuzzerLidV2.stl]
